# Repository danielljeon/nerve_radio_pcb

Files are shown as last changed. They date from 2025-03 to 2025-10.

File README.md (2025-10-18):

# nerve_radio_pcb



Radio and power supply module
to [`nerve_pcb`](https://github.com/danielljeon/nerve_pcb).

---

<details markdown="1">
  <summary>Table of Contents</summary>

<!-- TOC -->
* [nerve_radio_pcb](#nerve_radio_pcb)
  * [1 Overview](#1-overview)
  * [2 Board Specifications](#2-board-specifications)
    * [2.1 Connectors](#21-connectors)
    * [2.2 Switching Buck Regulator](#22-switching-buck-regulator)
  * [3 Release Notes](#3-release-notes)
    * [3.1 v0.1.0-alpha](#31-v010-alpha)
    * [3.2 v1.0.0 (WIP)](#32-v100-wip)
<!-- TOC -->

</details>

---

## 1 Overview

| Top | Bottom | v0.1.0-alpha |
|:---:|:---:|:---:|
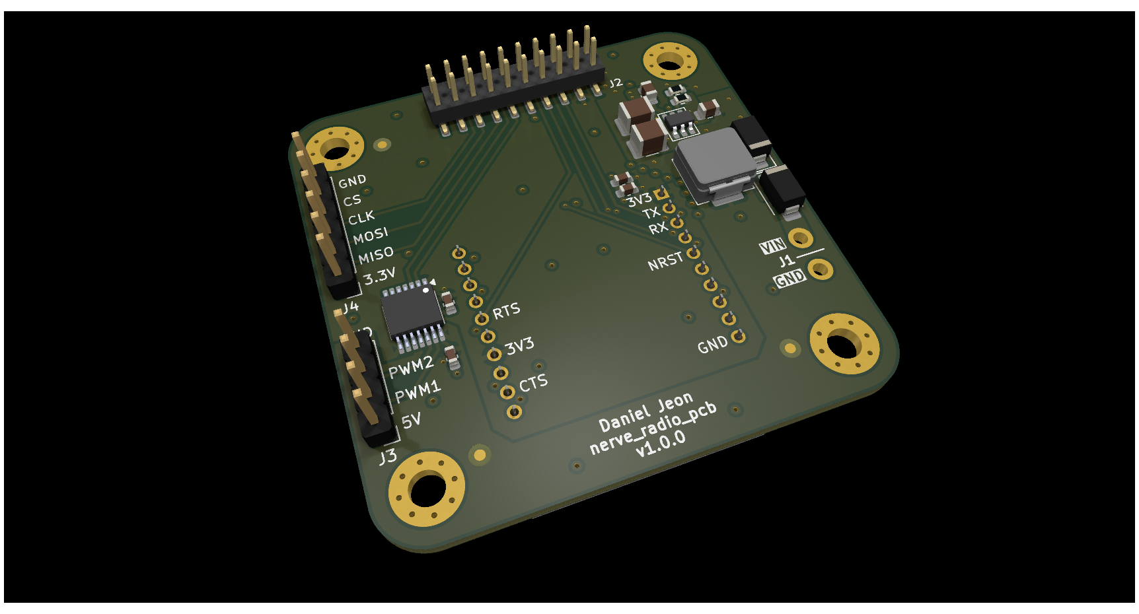
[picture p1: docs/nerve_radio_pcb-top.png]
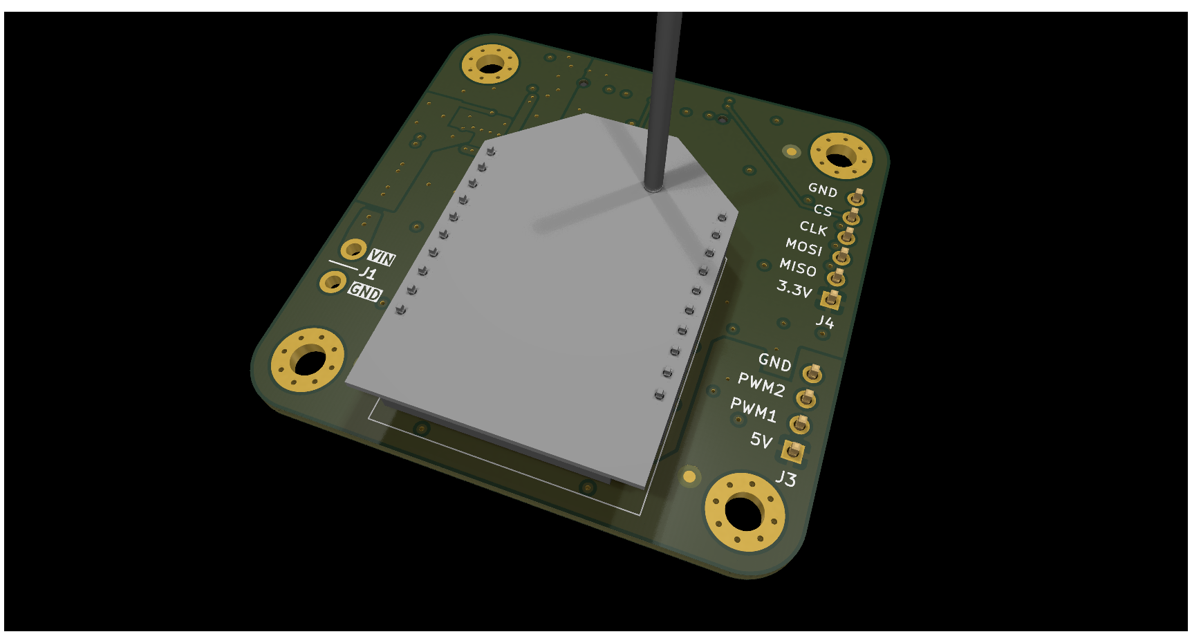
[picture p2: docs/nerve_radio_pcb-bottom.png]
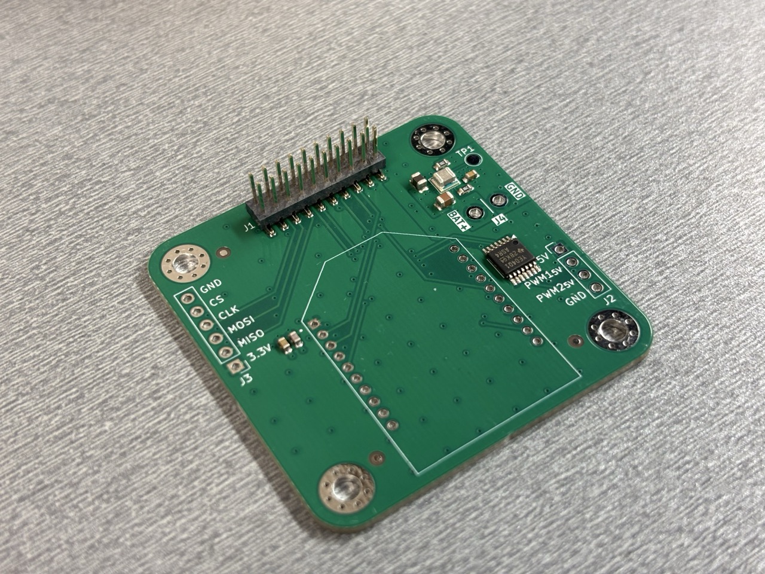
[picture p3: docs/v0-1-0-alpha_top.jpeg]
|  |  |  |

---

## 2 Board Specifications

### 2.1 Connectors

Connectors fixed by hardware (PCB traces or the connector itself).

| Connector | Ref | Description |
|---|:---:|---|
| LMR51430 buck (5 V) regulator | J1  | Pin 1: Ground, Pin 2: VIN supply (> 5 V, <= 36 V) |
| Bottom side 2x10 board-to-board | J2  | See schematic/layout for details |
| 5 V GPIO/PWM breakout | J3  | Pin 1: 5 V, Pin 2-3: GPIO/PWM 1-2 (5 V), Pin 5: Ground |
| SPI breakout | J4  | Pin 1: 3.3 V, Pin 2: MISO, Pin 3: MOSI, Pin 4: CLK, Pin 5: CS, Pin 6: Ground |

### 2.2 Switching Buck Regulator

The `LMR51430` is used for the 5 V (3 A) supply from a 4.5 V to 36 V input.

Also chosen based on previous experience and testing from a previous
project, [robotic_hand_pcb](https://github.com/danielljeon/robotic_hand_pcb).
See documentation
at [robotic_hand_pcb/blob/main/README.md#5-switching-buck-regulator](https://github.com/danielljeon/robotic_hand_pcb/blob/main/README.md#5-switching-buck-regulator).

---

## 3 Release Notes

### 3.1 v0.1.0-alpha

- Pre-release 4-layer board variant.
    - Short-term pre-release board bring-up/testing release.
- Order date: 2025/01/13.

### 3.2 v1.0.0 (WIP)

- Incremented major version since `v0.1.0-alpha` pre-release due to partial
  redesign including full component changes.
    - Buck converter redesign (TPSM843x20 -> LMR51430), reasoning:
        - Potential supply chain risks and cost.
        - Improved compatibility in common buck converter IC footprints.
        - Reduced restrictions on space allocated for power supply circuits.
        - Improved input voltage range (> 5 V, <= 36 V) -> (> 5 V, <= 17 V).
        - Easier to test due to exposed switch node.

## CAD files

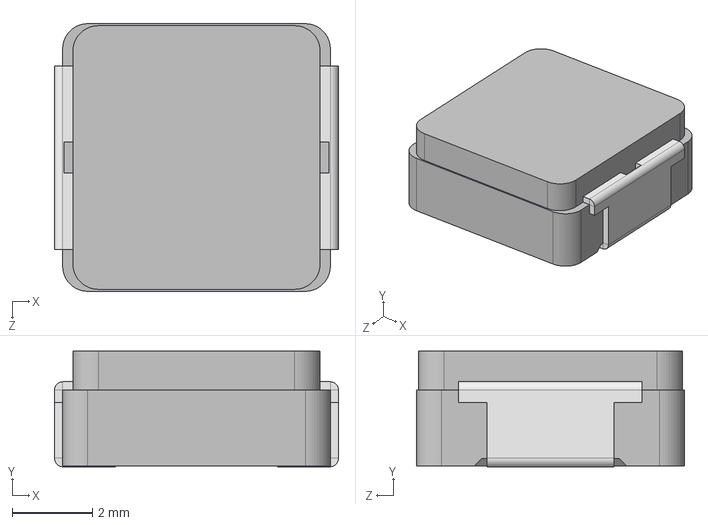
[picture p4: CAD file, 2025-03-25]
component_local/model_3d/IHLP2525CZ.step
7.08 x 2.88 x 6.67 mm

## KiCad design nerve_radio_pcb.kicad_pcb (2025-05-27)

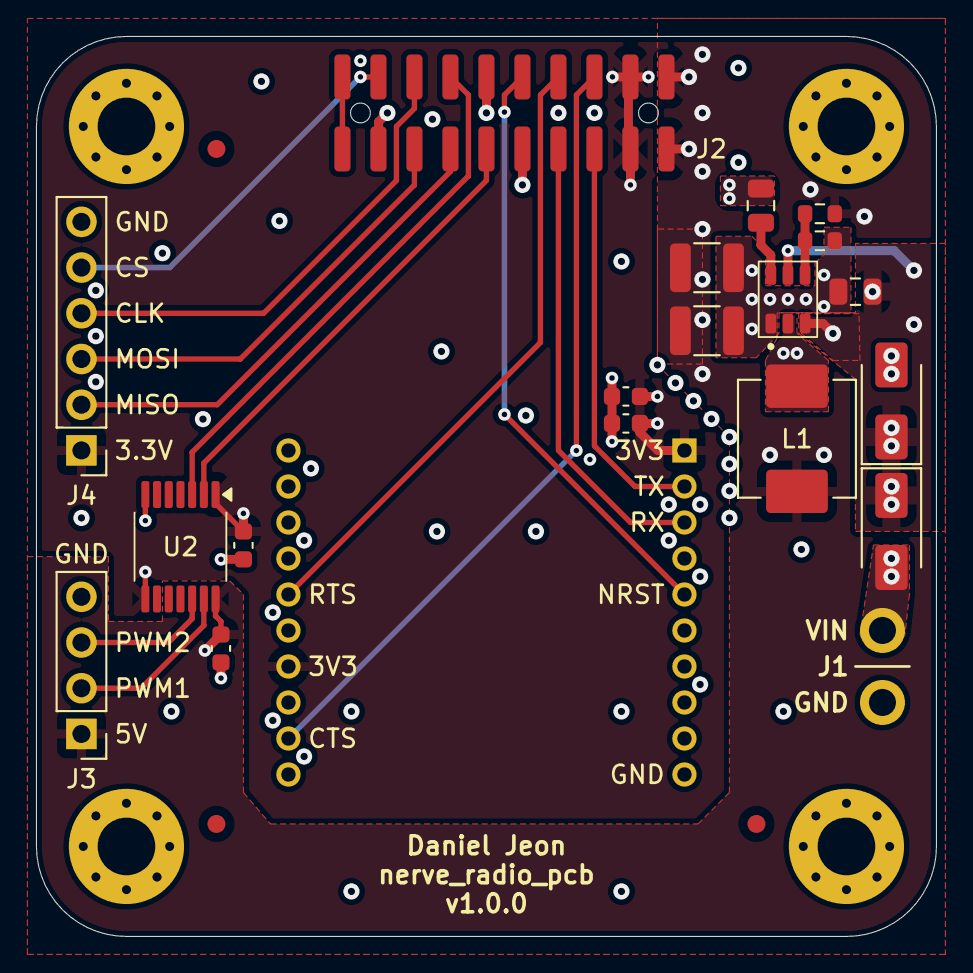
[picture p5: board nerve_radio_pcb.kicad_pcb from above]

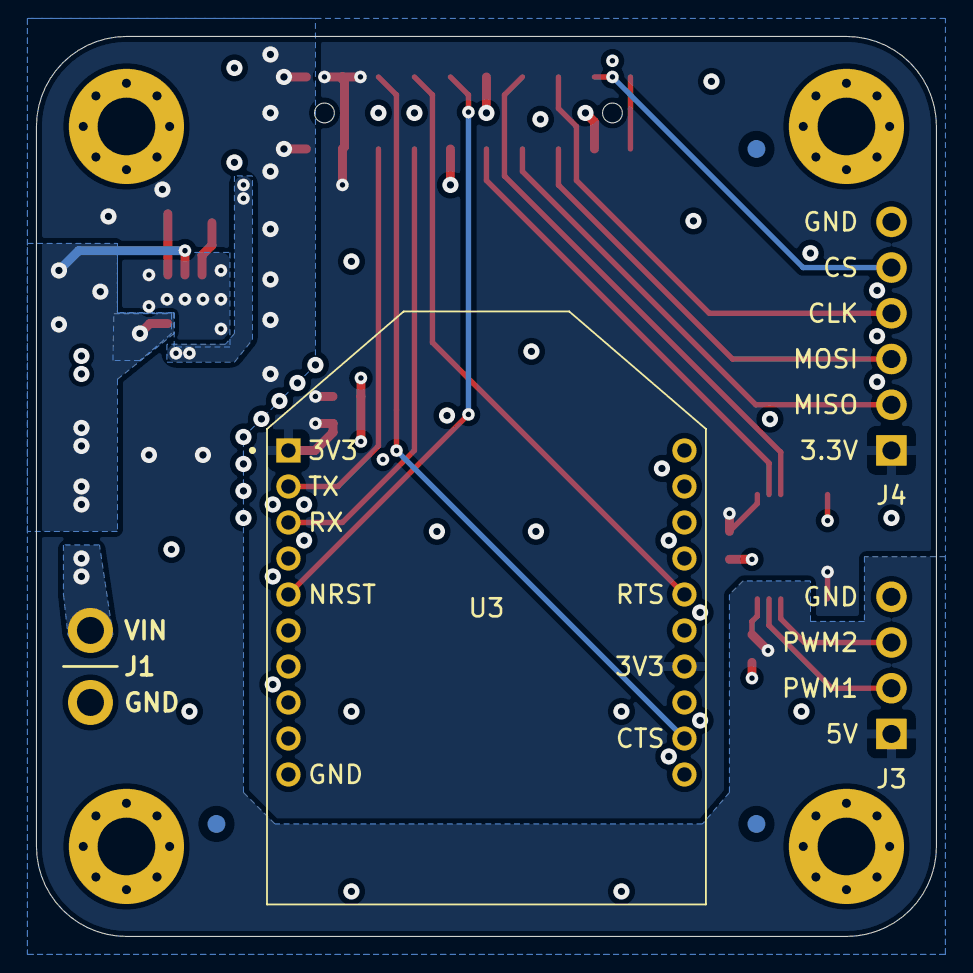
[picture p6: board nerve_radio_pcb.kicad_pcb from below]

Board: 4 copper layers, 50.0 x 50.0 mm, 30 parts (4 on the bottom side), 22 nets.

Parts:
C1: 100n; C_0805_2012Metric
C2, C3: 100n; C_0603_1608Metric
C4: 2u2; C_0805_2012Metric
C5, C6: 22u; C_1210_3225Metric
C7: 47p; C_0603_1608Metric
C8: 1u; C_0603_1608Metric
D1: SK36A-LTP; D_SMA
D2: SMAJ15A-13-F; D_SMA
FM1, FM2, FM3, FM4, FM5, FM6: 1mm; Fiducial_1mm_Mask2mm
H1, H2, H3, H4: M3; MountingHole_3.2mm_M3_Pad_Via
J1: Battery; battery
J2: BF030-20A-B1-0360-0277-0600-LB; bf030-20a-b1-0360-0277-0600-lb
J3: 5V GPIO Breakout; PinHeader_1x04_P2.54mm_Vertical
J4: 3V SPI Breakout; PinHeader_1x06_P2.54mm_Vertical
L1: 6u8; vishay_ihlp-2525cz
R1: 100k; R_0603_1608Metric
R2: 13k7; R_0603_1608Metric
U1: LMR51430; lmr51430
U2: TXB0104QPWRQ1; txb0104qpwrq1
U3: XBP9B-DMWT-002; xbee_pro_900hp

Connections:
+3V3: C2.1, C7.1, C8.1, J2.3, J2.4, J4.1, U2.1 (V_{CCA}), U2.8 (OE), U3.1 (VCC), U3.14 (VREF)
+5V: C3.1, C5.2, C6.2, J2.1, J2.2, J3.1, L1.2, R1.2, U2.14 (V_{CCB})
+VSUPPLY: C4.1, D1.1 (K), D2.1 (A1), U1.3 (VIN), U1.5 (EN)
/BUCK_SW: C1.2, L1.1, U1.2 (SW)
/GPIO_1/PWM_1: J2.11, U2.2 (A1)
/GPIO_1/PWM_1_{5V}: J3.2, U2.13 (B1)
/GPIO_2/PWM_2_{5V}: J3.3, U2.12 (B2)
/GPIO_2/PWM_2/ADC_DRDY: J2.14, U2.3 (A2)
/RADIO_NRST: J2.10, U3.5 (~RESET)
/RADIO_UART_CTS: J2.6, U3.12 (~CTS/DIO7)
/RADIO_UART_RTS: J2.8, U3.16 (~RTS/DIO6)
/RADIO_UART_RX: J2.7, U3.3 (DIN/~CONFIG/DIO14)
/RADIO_UART_TX: J2.5, U3.2 (DOUT/DIO13)
/SPI_CLK: J2.16, J4.4
/SPI_CS: J2.18, J4.5
/SPI_MISO: J2.13, J4.2
/SPI_MOSI: J2.15, J4.3
GND: C2.2, C3.2, C4.2, C5.1, C6.1, C7.2, C8.2, D2.2 (A2), H1.1, H2.1, H3.1, H4.1, J1.2, J2.9, J2.12, J2.17, J3.4, J4.6, R2.2, U1.1 (GND), U2.7 (GND), U3.10 (GND)
unnamed: D1.2 (A), J1.1
unnamed: J2.19, J2.20
unnamed: C1.1, U1.6 (CB)
unnamed: R1.1, R2.1, U1.4 (FB)

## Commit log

2024-11-18 Add WIP KiCad files
    [nerve_radio_pcb.kicad_pcb, nerve_radio_pcb.kicad_sch]
2024-11-18 Fix board-to-board connector pinout
    [nerve_radio_pcb.kicad_pcb, nerve_radio_pcb.kicad_sch]
2024-11-18 Move PCB dimensions to User Comments layer
    [nerve_radio_pcb.kicad_pcb]
2024-11-18 Pass DRC (ERC previously passed)
    [nerve_radio_pcb.kicad_pcb]
2024-11-19 Combine KiBot BoM directory
2024-11-19 Add stackup PCB notes
    [nerve_radio_pcb.kicad_pcb]
2024-11-19 Update KiBot PCB PDF gen
2024-11-20 Add ground stitching vias and silkscreen cleanup
    [nerve_radio_pcb.kicad_pcb]
2024-11-26 Widen 5V rail
    [nerve_radio_pcb.kicad_pcb]
2024-12-03 Add initial README.md and PCB pictures
2024-12-08 Cleanup revision and docs pictures
    [nerve_radio_pcb.kicad_pcb, nerve_radio_pcb.kicad_sch]
2024-12-13 Cleanup and update board-to-board connector
    [nerve_radio_pcb.kicad_pcb, nerve_radio_pcb.kicad_sch]
2024-12-13 Add missing connectors library record
2024-12-13 Regenerate PCB
    [nerve_radio_pcb.kicad_pcb]
2025-01-03 Update config.kibot.yaml, cleanup, add fiducials
    [nerve_radio_pcb.kicad_pcb, nerve_radio_pcb.kicad_sch]
2025-01-07 Update component_library and add 5V buck
    [nerve_radio_pcb.kicad_pcb, nerve_radio_pcb.kicad_sch]
2025-01-08 Cleanup and add missing transfer vias
    [nerve_radio_pcb.kicad_pcb]
2025-01-08 Remove unused via pads
    [nerve_radio_pcb.kicad_pcb]
2025-01-09 Major cleanup
    [nerve_radio_pcb.kicad_pcb]
2025-01-11 Cleanup and add battery connector
    [nerve_radio_pcb.kicad_pcb, nerve_radio_pcb.kicad_sch]
2025-01-13 Cleanup silkscreen
    [nerve_radio_pcb.kicad_pcb]
2025-01-16 Update component recommendation notes
    [nerve_radio_pcb.kicad_sch]
2025-01-16 Remove bad specific part suggestion notes
    [nerve_radio_pcb.kicad_sch]
2025-03-08 Redesign layout for WIP v0.1.0
    [nerve_radio_pcb.kicad_pcb, nerve_radio_pcb.kicad_sch]
2025-03-08 Shorten board-to-board connector
2025-03-08 Fix previous bad commit 14902c5
    [nerve_radio_pcb.kicad_pcb, nerve_radio_pcb.kicad_sch]
2025-03-25 Update buck converter for v1.0.0 dev
    - Update component library
    - Change buck regulator design to LMR51430
    - Cleanup PCB
    - Update version info
    [IHLP2525CZ.step, nerve_radio_pcb.kicad_pcb, nerve_radio_pcb.kicad_sch]
2025-04-03 Update for KiCad 9.0 and component library
    [nerve_radio_pcb.kicad_pcb, nerve_radio_pcb.kicad_sch]
2025-04-12 Update docs for LMR51430 buck
2025-04-21 Move UART RX/TX flip to board-to-board connector
    [nerve_radio_pcb.kicad_pcb, nerve_radio_pcb.kicad_sch]
2025-04-28 Add minor decoupling caps and TVS/Schottky diodes
    [nerve_radio_pcb.kicad_pcb, nerve_radio_pcb.kicad_sch]
2025-04-29 Improve current path vias
    [nerve_radio_pcb.kicad_pcb]
2025-05-14 Update README.md for PCB module reference
2025-05-14 Add TVS and schottky diode info
    [nerve_radio_pcb.kicad_pcb, nerve_radio_pcb.kicad_sch]
2025-05-27 Cleanup and fix outer layer non-functional pads
    [nerve_radio_pcb.kicad_pcb]
2025-06-03 Update config.kibot.yaml for KiCad/Bot 9
2025-10-18 Add board picture
